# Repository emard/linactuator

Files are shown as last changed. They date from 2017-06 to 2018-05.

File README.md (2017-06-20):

# Linear Actuator

Simple and cheap linear actuator with M4 threaded rod.
Inside are put 2 hex nuts and a spring between them.
Try rotating one nut in all 6 positions to experimentally
find best option, least fricition and still no gap.

This actuator should be a better replacement for factory 
default Z-actuator found in 3D printer "Turnigy Fabrikator ][ Mini".

Attached is also 3D printable removal tool to ease disassembling
factory default Z-actuator using a M4 screw to get original elongated M4 
brass nuts out of it.

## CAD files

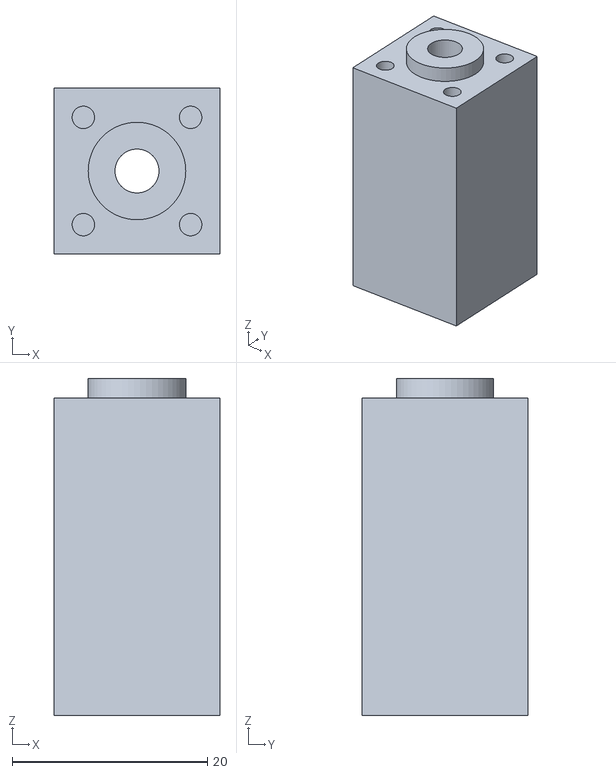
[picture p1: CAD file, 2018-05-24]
linactuator.stl
17.0 x 17.0 x 34.5

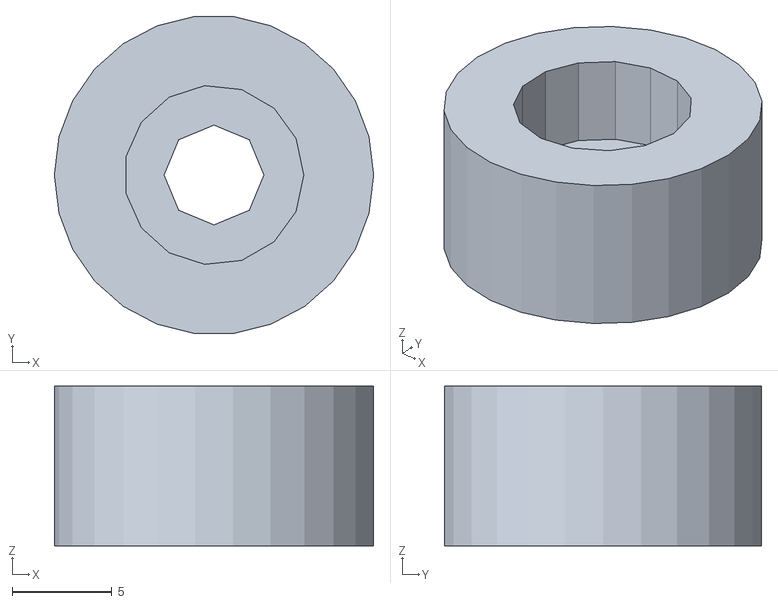
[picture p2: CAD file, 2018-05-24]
removal-tool.stl
16.0 x 15.9 x 8.00

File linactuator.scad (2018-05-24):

gore=1; // napravi gornji dio
dolje=0; // napravi donji dio
presjek=0; // vizualiziraj unutrasnjost
plocice=0;

podizac_xy=17;

sarafi_xy=11;
sarafi_navoj_d=2.3; // rupa za navoj sarafa
sarafi_navoj_h=15; // gornja dubina rupe
sarafi_prolaz_d=2.5; // poklopac
sarafi_plocice_d=2.1;
// sarafi_h=10; // dubina rupe za saraf
sarafi_navoj_d_dolje=1.8; // dolje za mali saraf
sarafi_navoj_h_dolje=15; // donja dubina rupe

krug_d=10;
krug_h=2;

rez_h=4; // dužina odrezanog dijela
rez_d=0.1; // veličina samog reza

matica_d=6.5;  // šitina 6-kutne rupe da matica lagano prođe. Matica je široka 6.0 mm
ulaz_matica_h=0.6; // dubina proširenog ulaza za maticu
ulaz_matica_d=matica_d+2*ulaz_matica_h; // veličina proširenog ulaza
//matica_h=22.4; // dubina rupe za 2 matice i feder (1 matica je dugačka 8.1 mm, neopterećen feder je 8 mm)
matica_h=2*8+17-4; // feder 17 mm
podizac_h=matica_h+7.6;
sipka_d=4.5; // rupa za navojnu šipku, dosta lufta
prijelaz_h=matica_d-sipka_d; // visina konusnog 6-kutnog prijelaza od matice prema rupi za šipku da ne padnu slojevi

if(gore > 0.5 || dolje > 0.5)
union()
{
  difference()
  {
    union()
    {
      cube([podizac_xy, podizac_xy,podizac_h],center=true);
      translate([0,0,podizac_h/2+krug_h/2])
        cylinder(d=krug_d,h=krug_h,$fn=50,center=true);
    }  
    union()
    {
      // sarafi kroz sve
      for(i=[0:3])
        rotate([0,0,90*i])
        {
          // navoj sarafa (gore)
          translate([sarafi_xy/2,sarafi_xy/2,podizac_h/2-sarafi_navoj_h/2])
            cylinder(d=sarafi_navoj_d,h=sarafi_navoj_h+0.001,$fn=50,center=true);
          // navoj sarafa (dolje)
          translate([sarafi_xy/2,sarafi_xy/2,-podizac_h/2+sarafi_navoj_h_dolje/2])
            cylinder(d=sarafi_navoj_d_dolje,h=sarafi_navoj_h_dolje+0.001,$fn=50,center=true);
          // rupa kroz donji odrezani dio
          translate([sarafi_xy/2,sarafi_xy/2,-podizac_h/2+rez_h/2])
            cylinder(d=sarafi_prolaz_d,h=rez_h+0.001,$fn=50,center=true);
  
        }
      // rez koji odvaja 2 dijela polovice
      translate([0,0,-podizac_h/2+rez_h])
        cube([podizac_xy,podizac_xy,rez_d],center=true);

      // skorz uklonit donji dio
      if( dolje == 0 )
      {
        translate([0,0,-podizac_h/2+rez_h/2])
          cube([podizac_xy+0.001,podizac_xy+0.001,rez_h+0.001],center=true);
      }

      // skorz uklonit gornji dio
      if( gore == 0 )
      {
        translate([0,0,-podizac_h/2+rez_h+(podizac_h+krug_h-rez_h)/2])
          cube([podizac_xy+0.001,podizac_xy+0.001,(podizac_h+krug_h-rez_h)+0.001],center=true);
      }

      // rupa za navojnu šipku
      cylinder(d=sipka_d,h=2*podizac_h,$fn=50,center=true);

      // 6-kutna rupa za matice
      translate([0,0,(-podizac_h/2+rez_h)+matica_h/2])
        cylinder(d=matica_d*2/sqrt(3),h=matica_h+0.001,$fn=6,center=true);

      // konusni 6-kutni prošireni ulaz za matice
      translate([0,0,(-podizac_h/2+rez_h)+ulaz_matica_h/2])
        cylinder(d1=ulaz_matica_d*2/sqrt(3),d2=matica_d*2/sqrt(3),h=ulaz_matica_h+0.001,$fn=6,center=true);

      // konusni 6-kutni prijelaz od matice prema rupi,
      // da ne padnu isprintani slojevi
      translate([0,0,(-podizac_h/2+rez_h)+matica_h+prijelaz_h/2])
        cylinder(d1=matica_d*2/sqrt(3),d2=sipka_d,h=prijelaz_h+0.001,$fn=6,center=true);
      
      // kocka za presjek radi vizualizacije unutrasnjosti
      if(presjek)
      translate([podizac_xy/2,0,0])
      cube([podizac_xy,podizac_xy+0.01,podizac_h*2],center=true);
    }
  }
}

module spaceri()
{
  d=[0.5,1,2];
  for(i = [0:len(d)-1])
  {
    translate([podizac_xy*1.5*(i-1),0,d[i]/2])
      difference()
      {
        cube([podizac_xy,podizac_xy,d[i]],center=true);
        // 6-kutne rupe za maticu
        cylinder(d=matica_d*2/sqrt(3),h=d[i]+0.001,$fn=6,center=true);
      // sarafi kroz sve
        for(j=[0:3])
          rotate([0,0,90*j])
          {
          translate([sarafi_xy/2,sarafi_xy/2,0])
            cylinder(d=sarafi_plocice_d,h=d[i]+0.001,$fn=50,center=true);
              // 
          }
      }
  }
}

if(plocice > 0.5)
    spaceri();

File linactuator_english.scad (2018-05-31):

up=1; // make the upper part, enable with 1, disable with 0
down=1; // make the bottom, enable with 1, disable with 0
cut=1; // visualize the interior, enable with 1, disable with 0
tiles=1; // spacers with different thickness, enable with 1, disable with 0

lifter_xy=17;

screw_xy=11;
screw_thread_d=2.3; // hole for screw thread
screw_thread_h=15; // upper hole depth
screw_passage_d=2.5; // cover
screw_tiles_d=2.1;
// screw_h=10; // depth of the hole for the screw
screw_thread_d_down=1.8; // down for a little screw
screw_thread_h_down=15; // lower depth of the hole

circle_d=10;
circle_h=2;

cut_h=4; // length of the cut part
cut_d=0.1; // the size of the cut

nut_d=6.5;  // a 6-angular hole of the hole that the nut passes smoothly. The nuts are 6.0 mm wide
entrance_nut_h=0.6; // depth of the extended input for the nut
entrance_nut_d=nut_d+2*entrance_nut_h; // the size of the extended input
//nut_h=22.4; // depth of hole for 2 nuts and feder (1 nuts is 8.1 mm long, unloaded feder is 8 mm)
nut_h=2*8+17-4; // feder 17 mm
lifter_h=nut_h+7.6;
rod_d=4.5; // hole for the threaded rod, a lot of lufts
transition_h=nut_d-rod_d; // the height of the conical 6-angular transition from the nut to the hole for the bar to avoid falling down the layers

if(up > 0.5 || down > 0.5)
union()
{
  difference()
  {
    union()
    {
      cube([lifter_xy, lifter_xy,lifter_h],center=true);
      translate([0,0,lifter_h/2+circle_h/2])
        cylinder(d=circle_d,h=circle_h,$fn=50,center=true);
    }  
    union()
    {
      // screw through everything
      for(i=[0:3])
        rotate([0,0,90*i])
        {
          // screw thread (up)
          translate([screw_xy/2,screw_xy/2,lifter_h/2-screw_thread_h/2])
            cylinder(d=screw_thread_d,h=screw_thread_h+0.001,$fn=50,center=true);
          // screw thread (down)
          translate([screw_xy/2,screw_xy/2,-lifter_h/2+screw_thread_h_down/2])
            cylinder(d=screw_thread_d_down,h=screw_thread_h_down+0.001,$fn=50,center=true);
          // hole through the lower part cut
          translate([screw_xy/2,screw_xy/2,-lifter_h/2+cut_h/2])
            cylinder(d=screw_passage_d,h=cut_h+0.001,$fn=50,center=true);
  
        }
      // a cut that separates 2 parts of the half
      translate([0,0,-lifter_h/2+cut_h])
        cube([lifter_xy,lifter_xy,cut_d],center=true);

      // the cortex will remove the lower part
      if( down == 0 )
      {
        translate([0,0,-lifter_h/2+cut_h/2])
          cube([lifter_xy+0.001,lifter_xy+0.001,cut_h+0.001],center=true);
      }

      // the cortex will remove the lower part
      if( up == 0 )
      {
        translate([0,0,-lifter_h/2+cut_h+(lifter_h+circle_h-cut_h)/2])
          cube([lifter_xy+0.001,lifter_xy+0.001,(lifter_h+circle_h-cut_h)+0.001],center=true);
      }

      // hole for threaded rod
      cylinder(d=rod_d,h=2*lifter_h,$fn=50,center=true);

      // 6-angular hole nuts
      translate([0,0,(-lifter_h/2+cut_h)+nut_h/2])
        cylinder(d=nut_d*2/sqrt(3),h=nut_h+0.001,$fn=6,center=true);

      // conical 6-angular extended input for nuts
      translate([0,0,(-lifter_h/2+cut_h)+entrance_nut_h/2])
        cylinder(d1=entrance_nut_d*2/sqrt(3),d2=nut_d*2/sqrt(3),h=entrance_nut_h+0.001,$fn=6,center=true);

      // conical 6-angular transition from nut to hole,
      // that the printed layers do not fall
      translate([0,0,(-lifter_h/2+cut_h)+nut_h+transition_h/2])
        cylinder(d1=nut_d*2/sqrt(3),d2=rod_d,h=transition_h+0.001,$fn=6,center=true);
      
      // a cube for the intersection to visualize the interior
      if(cut)
      translate([lifter_xy/2,0,0])
      cube([lifter_xy,lifter_xy+0.01,lifter_h*2],center=true);
    }
  }
}

module spacers()
{
  d=[0.5,1,2];
  for(i = [0:len(d)-1])
  {
    translate([lifter_xy*1.5*(i-1),0,d[i]/2])
      difference()
      {
        cube([lifter_xy,lifter_xy,d[i]],center=true);
        // 6-angular holes for the nut
        cylinder(d=nut_d*2/sqrt(3),h=d[i]+0.001,$fn=6,center=true);
      // screw through everything
        for(j=[0:3])
          rotate([0,0,90*j])
          {
          translate([screw_xy/2,screw_xy/2,0])
            cylinder(d=screw_tiles_d,h=d[i]+0.001,$fn=50,center=true);
              // 
          }
      }
  }
}

if(tiles > 0.5)
    spacers();

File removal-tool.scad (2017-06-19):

difference()
{
  cylinder(d=16,h=8,center=true);
  union()
  {
    cylinder(d=5,h=20,center=true);
    translate([0,0,3])
      cylinder(d=9,h=7,center=true);
  }
}

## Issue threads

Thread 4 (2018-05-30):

Usefulness with original 1part brass nut?

3DSTB, 2018-05-30:
I already have a brass nut on the top part of the z-screw with almost no play.
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
Is it still usefull to upgrade to the linactuator?

My brass nut is in a black plastic housing and this is mounted with 4 screws from the top. Why are there 4 screws on the bottom of the linactuator?

emard, 2018-05-30:
HI

This original assembly will slowly degrade over time, let's say
after printing first 1kg of filament it will surely need maintenance.

If zleveler is used, It won't work correctly first layer wont stick
reliably.

Lower 4 screws are for the plastic cover that completely closes linactuator
from bottom side, it should be 3D printed too otherwise brass nut will
leave it :)

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

3DSTB, 2018-05-30:
Hi,
thanks. Here is a drawing as i understand it now:
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
I found here that the spring should be 1cm long:
http://radiona.org/wiki/inventory/fabrikator_2_mini
Is that correct and not to short?
Can you please upload the file for the bottom Cover?

emard, 2018-05-30:
Yes that schematics depcits correct assembly and spring must
really be

1. short (0.5-1 cm)
2. weak spring (weakest possible force per mm of compression)

The spring crompression should be very little, maybe 1 mm.
If spring is compressed too tight, friction and material wear
will increase without any other benefit to the function.

Normally it is possible to cut springs short, and it will also work

If spring is too long then whole actuactor must be longer and
it won't fit to the 3D printer Z axis

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

3DSTB, 2018-05-30:
Tanks!
What is the reference for the spring lenght (should the compressed or the uncompressed lenght be 0.5 to 1cm)?

emard, 2018-05-30:
For fixed spring length, you can experiment 3D printing
varoios actuator lengths or spacers to adjust optimal length
to given spring.

You will feel it on your hand the Z-leadscrew
assembly is easy to rotate without any significant
friction and the should have zero "airgap" in up-down direction
so small that is impossible to feel it by the hand.

If it's too hard to rotate or has the gap, rotate one of the nuts and
try again. If can't go this way, then decrease spring compression strength

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

3DSTB, 2018-05-30:
Ok, i have now a spring which is 0.8x6x10 which is may be ok. There is enough  room to play with the compression.

3DSTB, 2018-05-30:
Last question:
Can you please upload your scad file for the plastic cover? May it is easier to just modify your file.
Thanks!

emard, 2018-05-30:
It is on the scad already, check out the source

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

Closed 2018-05-30.

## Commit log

2017-06-16 pocetna verzija podizaca
    [zpodizac.scad]
2017-06-16 popravljena parametrizacija unutarnje matice
    [zpodizac.scad]
2017-06-16 bolje mjere, popravak reza
    [zpodizac.scad]
2017-06-16 jos malo korigirane mjere nije isprobano za pravo
    [zpodizac.scad]
2017-06-17 konusni prijelaz od matice prema rupi za navojnu šipku
    [zpodizac.scad]
2017-06-17 povećana 6-kutna rupa 7.0->7.2 mm da matica glatko ide i proširen ulaz za maticu 8mm zato što prvi sloj bude isprintan nešto širi od ostalih slojeva
    [zpodizac.scad]
2017-06-19 proširene 4 rupe na donjem poklopcu da šarafi prođu
    [zpodizac.scad]
2017-06-19 alat za izvlačenje matice iz originalnog podizača
    [izvlakac.scad]
2017-06-19 poboljšane mjere
    [zpodizac.scad]
2017-06-19 tolerancije kad treba obrisat gornji ili donji dio
    [zpodizac.scad]
2017-06-19 fino štelanje mjere
    [zpodizac.scad]
2017-06-20 vise materijala gore da se mali krug ne odlomi i povećana dužina da opruga nije prejako napeta ovaj dizajn je ugrađen u printer sa palmom mali problem - padnu neki slojevi kod suženja prema gore
    [zpodizac.scad]
2017-06-20 blaži prijelaz da ne padnu slojevi
    [zpodizac.scad]
2017-06-20 readme about removal tool
    [linactuator.scad, removal-tool.scad]
2018-01-07 changing depth of the inner hole changes accordingly the total length of the actuator.
    [linactuator.scad]
2018-01-07 option to make cross-section to visualise the interior
    [linactuator.scad]
2018-01-09 adapter for 28mm long sping
    [linactuator.scad]
2018-01-11 update for trim spacers
    [linactuator.scad]
2018-01-12 reduce screws holes for better centering of bottom part
    [linactuator.scad]
2018-01-13 max length of spring is 17mm otherwise linear actuator will be too long to fit into the printer
    [linactuator.scad]
2018-05-24 Update linactuator.scad
    corrected typo
    [linactuator.scad]
2018-05-24 STL files
    stl files for the slicer
    [linactuator.stl, removal-tool.stl]
2018-05-30 english translation
    [linactuator_english.scad]
2018-05-31 english version spaceri->spacers
    [linactuator_english.scad]
